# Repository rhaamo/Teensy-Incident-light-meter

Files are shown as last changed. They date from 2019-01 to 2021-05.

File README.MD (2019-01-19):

Teensy Light Meter
--------

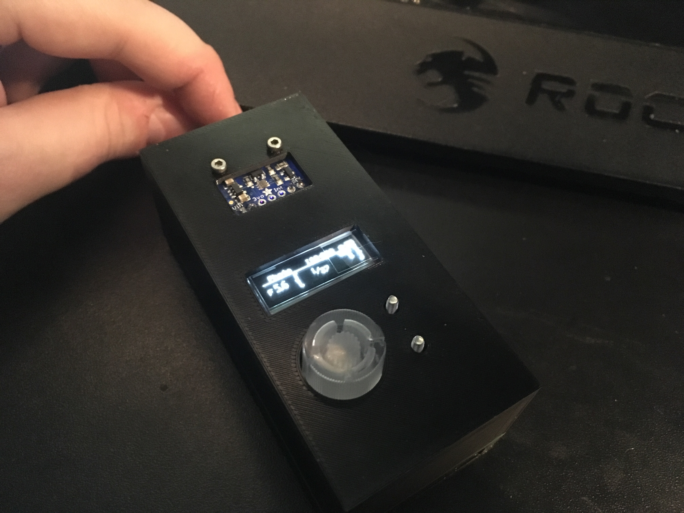
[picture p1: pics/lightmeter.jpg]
Product


### Links

 * <a href="./CALIBRATION.md">Calibration and notes</a>
 * <a href="./USAGE.md">How to use the firmware</a>
 * See the pics folder for more pictures

### Software

    $ git clone
    $ cd project/LightMeterV2
    $ pio lib install
    $ pio run
    $ pio run --target upload

Notes:
  The TSL25x1 lib I use is either custom, or hacked from anoter one. We setup the sensor and powerup on setup(), then let it run freely.

  The sensor do it's integration time by itself, we NEVER poweroff the sensor, then we read the value as the loop loops.

  This is done to avoid the 120ms*integrationTime etc. delay, the loop is ultra fast, then buttons are reactive.

  And we can then set the sensor to a high integration value without having 500ms delay introduced in the loop.

### Notes

The Light Meter isn't super slim, but not too big, it could get 5mm less easily if the pins connecting the teensyview were trimmed.

Without trimming everything used is stock without modifications. Also the OLED display PCB is way bigger than the LCD itself, and that forbig to reduce by ~3mm without having an ugly PCB popping out. Trimming the pins will be envisaged in the future.

The choosen battery was a BL-5C because I have one spare, but any with a JST connector would do the job, only the middle part and bottom of the enclosure would need redesign. The battery connector is some sort of wire bended, passed through a hole and glued after soldering. Not the best but I didn't wanted to wait a month to get a small 3-pins 3mm pitch battery connector to design the enclosure.

The stock BL-5C, genuine, is a 1000mAh battery, the Light Meter, with sensor free-running is consuming about 40mA according to the battery charger, which allows between 17 and 25 hours of continus running, in theory. You can still easily swap battery anyway, just bring the right screwdriver, and spare charged batteries with you.

The USB data is hard wired between the D+/D- pads of the teensy to the battery babysitter, allowing to program the teensy from the battery charger directly without doing anything, reset button is useless as we are using the stock teensy bootloader, permitting remote flash and reboot.

The TSL2591 doesn't permit changing I2C address, you can only have one.

### Todo

 - Design some sort of sliding window to protect the sensor
 - Games, because why not ?

### Hardware

Uses the following:

* [Teensy 3.2](https://www.sparkfun.com/products/13736)
* [TeensyView](https://www.sparkfun.com/products/14048) (ALTERNATE mode)
* [TSL2591 HDR Light Sensor](https://www.adafruit.com/product/1980)
* [Battery Babysitter](https://www.sparkfun.com/products/13777)
* [Rotary Encoder with Red/Green led](https://www.digikey.fr/product-detail/fr/bourns-inc/PEL12D-4225S-S2024/PEL12D-4225S-S2024-ND/2498880)
* [Knob, transparent](https://www.digikey.fr/product-detail/fr/sparkfun-electronics/COM-10597/1568-1838-ND/7229845)
* Battery: BL-5C (1000mAh nokia battery)
* Mini switch: 6mm push button
* Diode: 1N4148
* Transistor: 2N3940, TO-92
* Resistor: 4.7k
* Capacitor: 10uF, radial, polarised
* A PCB from the PCB folder

Some build notes :
 - The battery can be either connected from the JST connector (DIY enclosure) or from the pads right next to it (provided enclosure)
 - The D+ and D- from USB should be soldered on the teensy first before soldering it to the PCB, make sure to mark with a marker the D- wire. Then after soldering the teensy and the babysitter, twist the two DATA wires and solder them accordingly to the babysitter very small pads.
 - The TSL2591 use four wire (Vcc, GND, SDA, SCL) and ideally use two small connectors, allowing for quick disconnect, for either hacking or easy replacement.
 - The TeensyView needs to be in ALTERNATE mode, cut some jumper pads and solder the others before sticking the OLED glass. Look at Sparkfun docs for that part.
 - The Alternate mode is unfortunately needed because of the pins 10 & 11 which are already used for the RED and Green LEDs. A next revision can change that.
 - The TeensyView pins are connected by using standard "long" headers, see ```pics/main_pcb_battery_babysitter.jpg``` for soldering. Also you will have to trim the headers by 5mm on top, to make the display closed to the teensy.
 - You have to put the battery babysitter switch to the OFF position, or it will override the power-on/off feature.

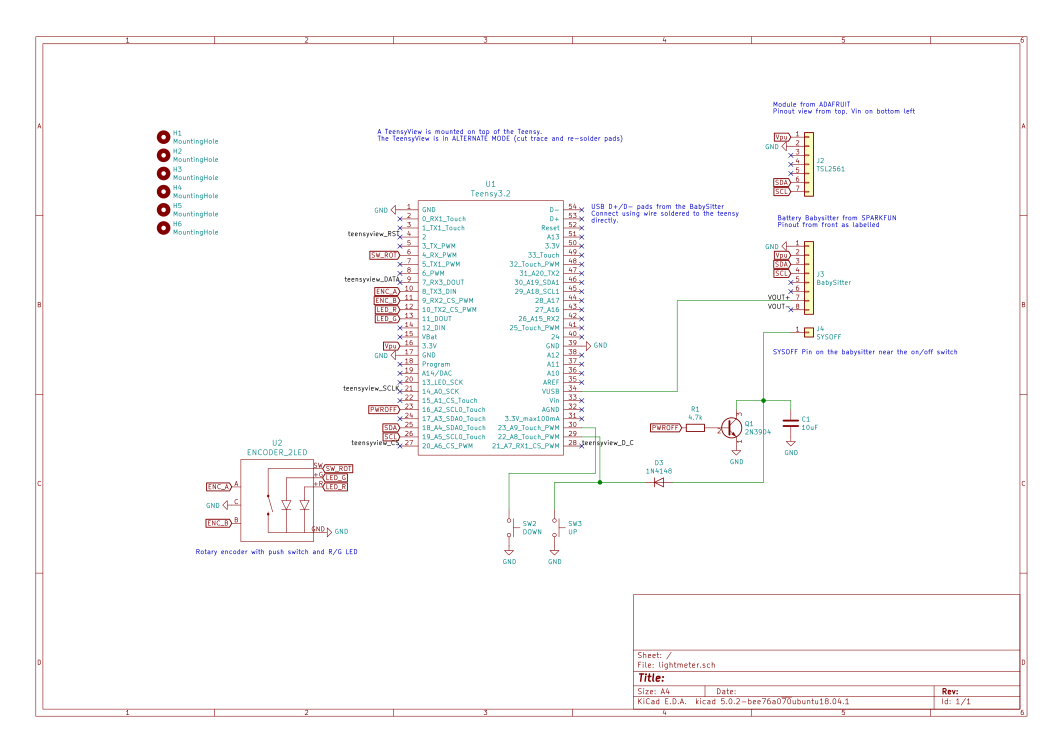
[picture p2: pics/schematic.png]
Schematic


*Schematic diagram.  Click to enlarge.*

### Enclosure

3D designed, printed, works great, to be published.

### PCB

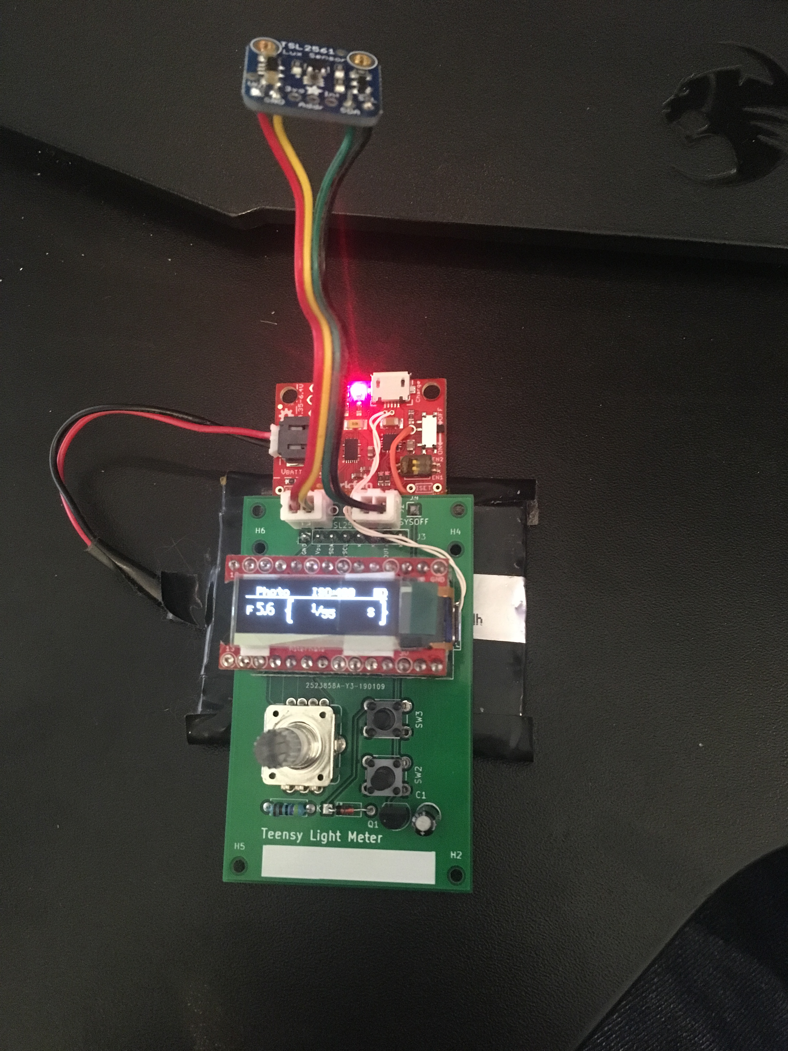
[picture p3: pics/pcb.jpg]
Innards


*An assembly*

 * Use libraries:
  * https://github.com/XenGi/teensy.pretty
  * https://github.com/XenGi/teensy_library
  * RGB Encoder Footprint and Library from https://github.com/sparkfun/Rotary_Encoder_Breakout-Illuminated

### License

Uses code from:
  * https://github.com/marshalltaylorSFE/Teensy-Incident-light-meter
  * https://github.com/kevinagnes/diycolorlightmeter/

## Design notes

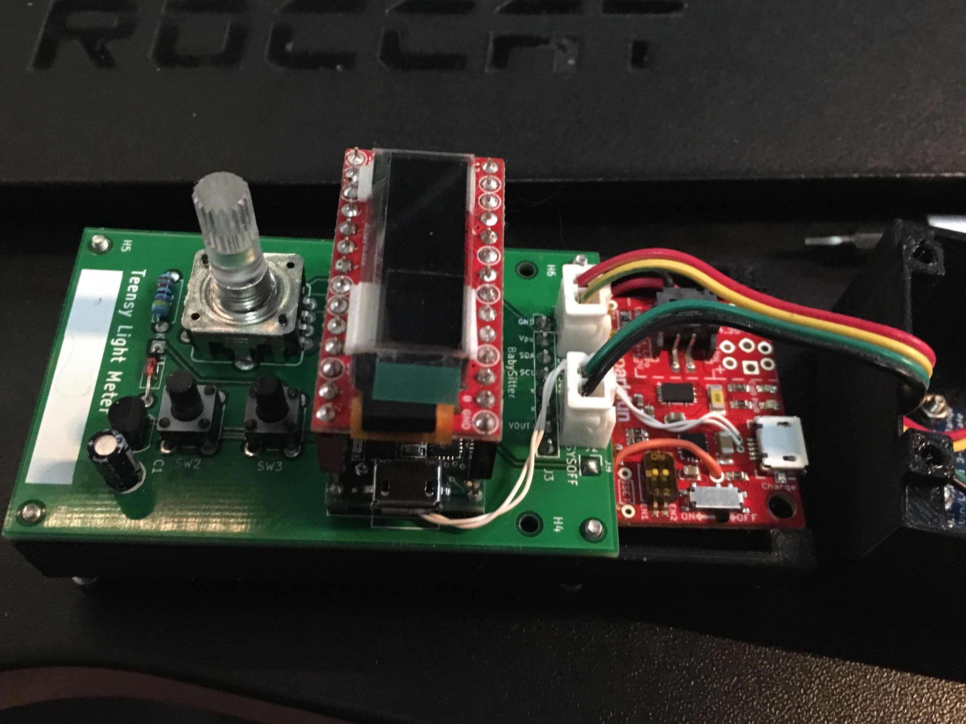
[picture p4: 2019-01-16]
pics/pcb_built_closeup.jpg

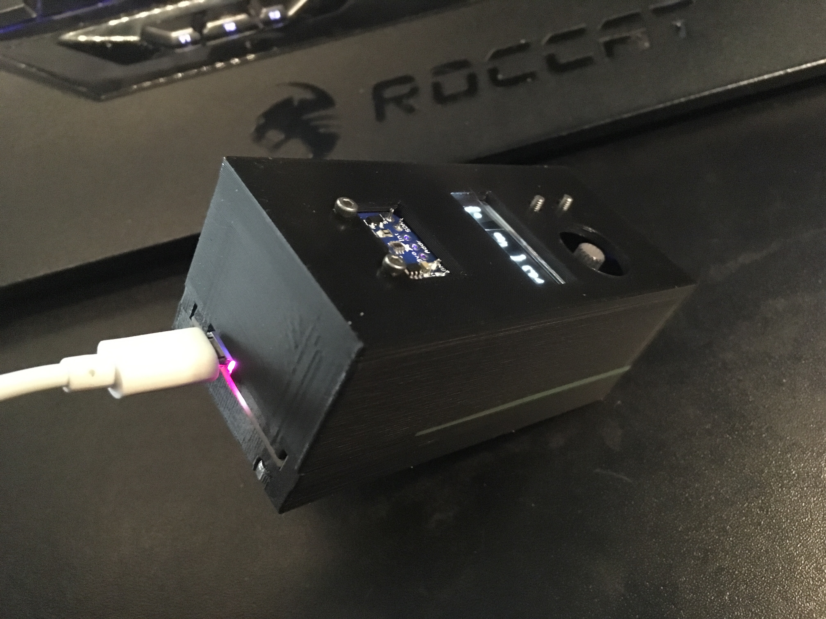
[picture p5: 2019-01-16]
pics/usb_charge.jpg

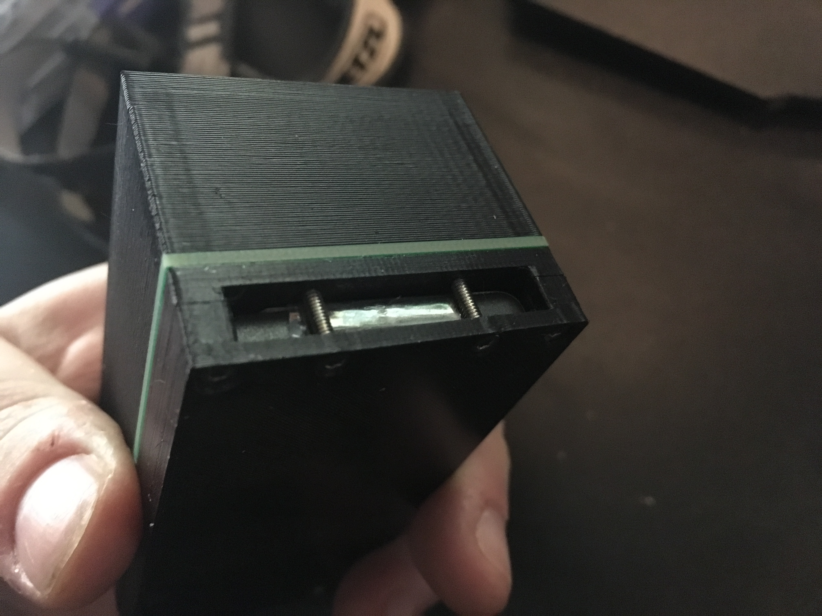
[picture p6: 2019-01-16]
pics/battery_retainer.jpg

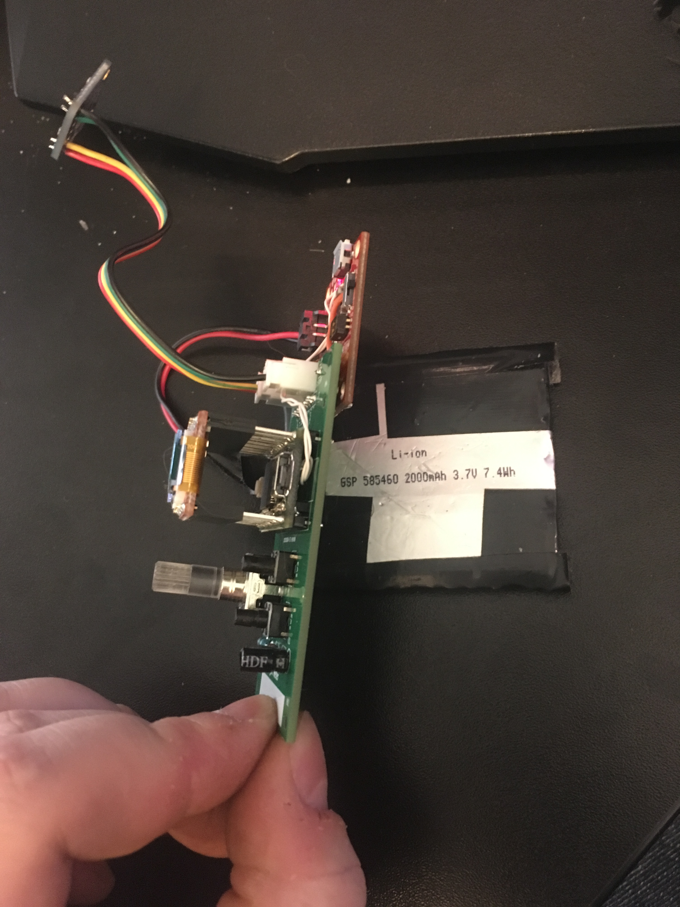
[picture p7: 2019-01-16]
pics/main_pcb_battery_babysitter.jpg

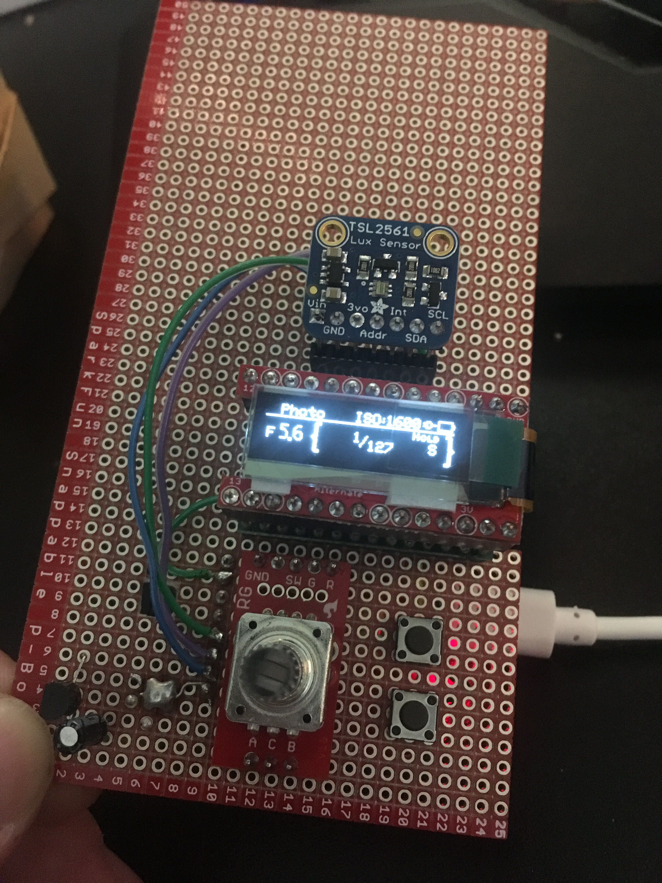
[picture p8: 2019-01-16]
pics/prototype.jpg

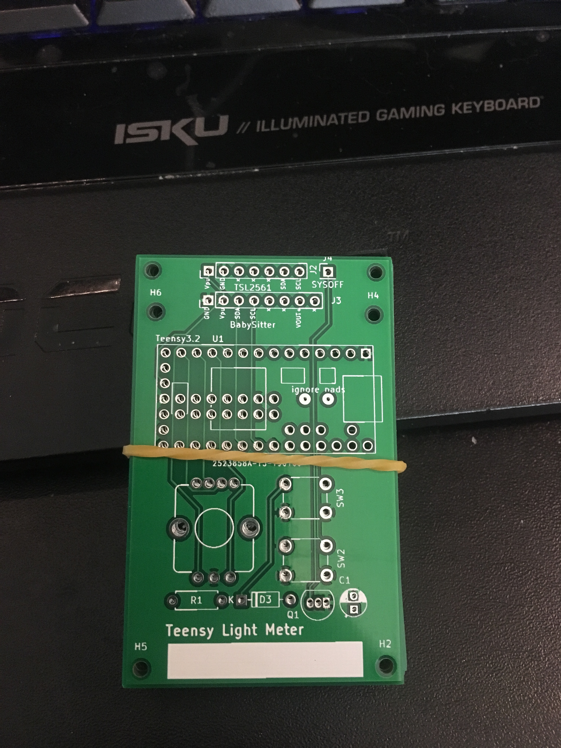
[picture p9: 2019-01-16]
pics/main_pcb.jpg

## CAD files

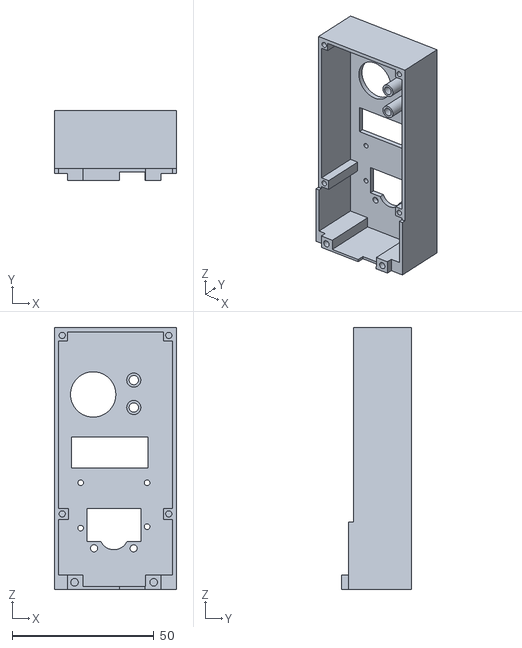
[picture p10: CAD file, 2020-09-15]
enclosure_v1/top.stl
43.2 x 24.6 x 92.5

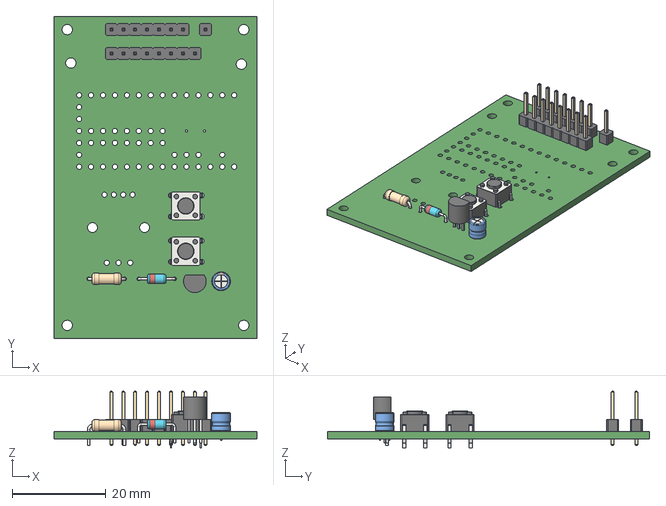
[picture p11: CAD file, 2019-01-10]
PCB/lightmeter.step
43.2 x 68.6 x 12.0 mm

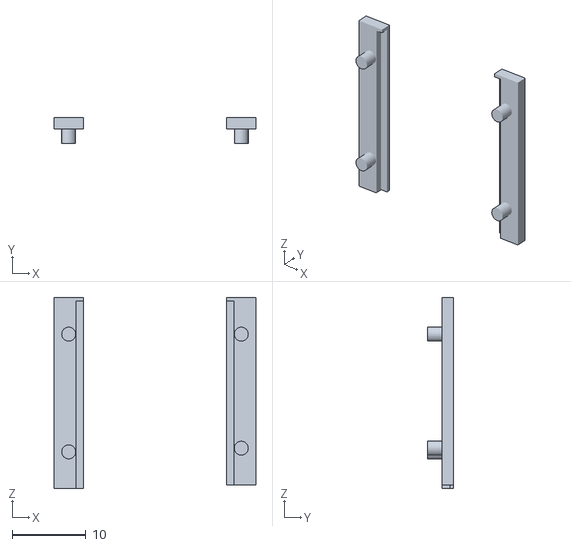
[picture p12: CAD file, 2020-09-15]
enclosure_v1/cover slides.stl
27.4 x 3.60 x 26.0

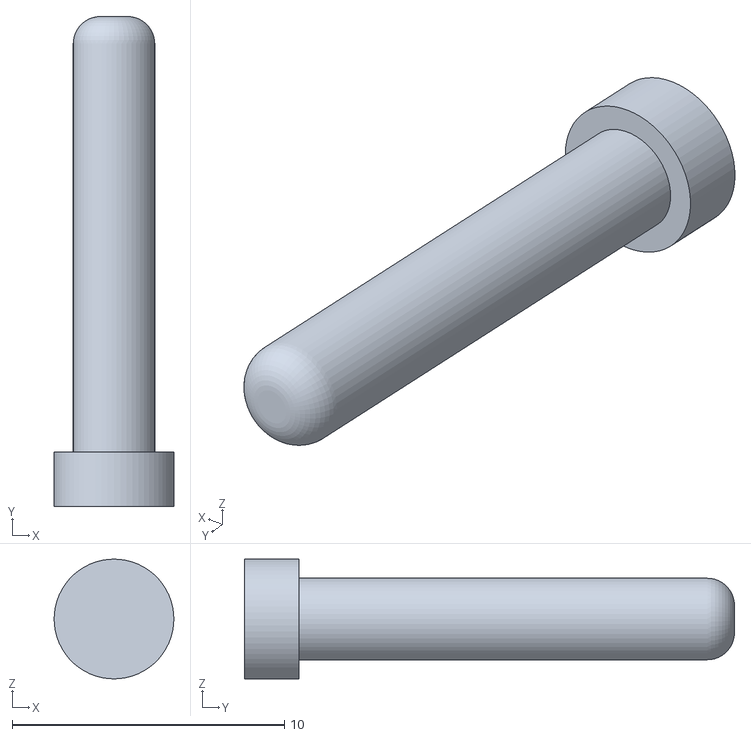
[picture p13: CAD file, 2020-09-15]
enclosure_v1/pb_extender_x2.stl
4.40 x 18.0 x 4.40

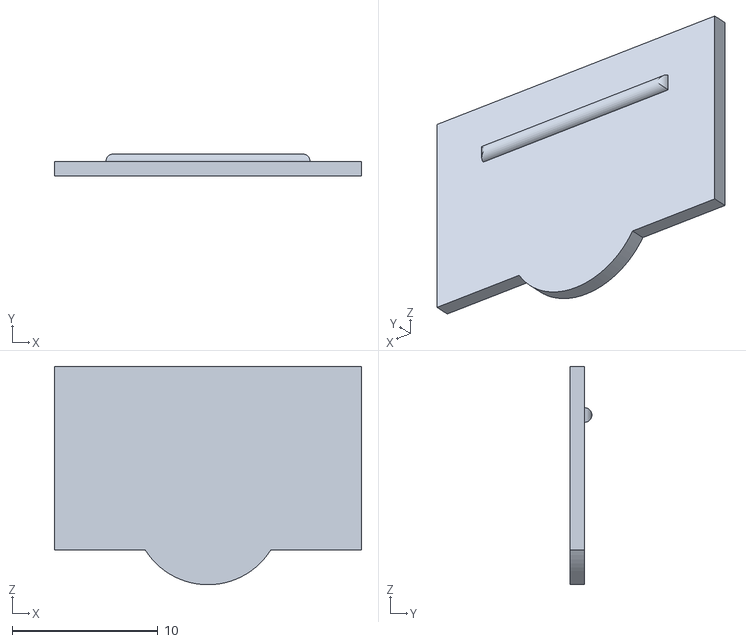
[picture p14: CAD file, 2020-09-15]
enclosure_v1/cover.stl
21.1 x 1.50 x 15.0

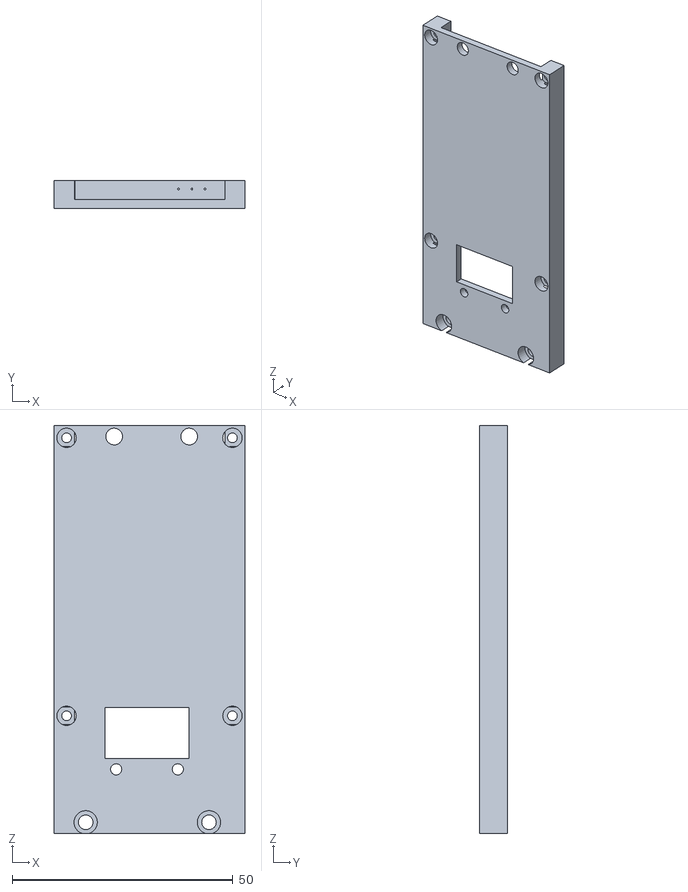
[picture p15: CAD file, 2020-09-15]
enclosure_v1/bottom.stl
43.2 x 6.30 x 92.5

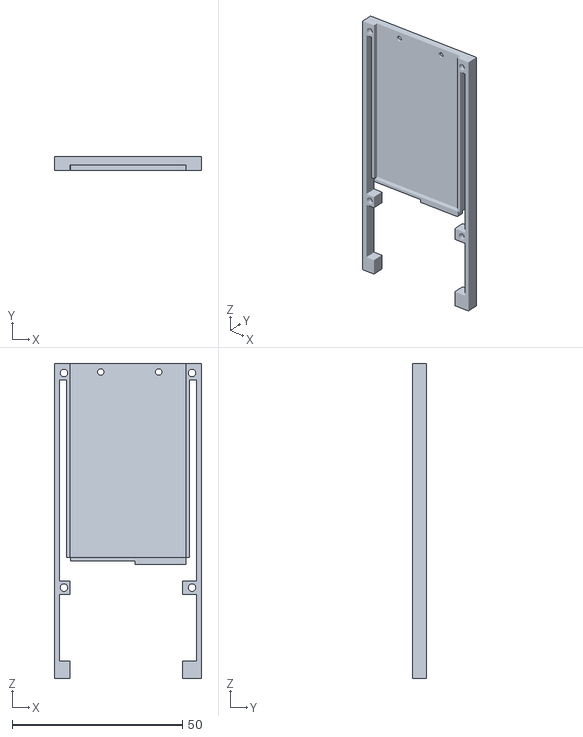
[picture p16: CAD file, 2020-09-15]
enclosure_v1/middle.stl
43.2 x 4.10 x 92.5

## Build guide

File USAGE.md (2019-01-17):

# Usage of the Light Meter firmware

## Physical

The encoder is also a push-button, and made to be translucent as the cap, and lighted with a RED and GREEN leds.

The top button is the power-on, and previous-menu, the bottom one is next-menu.

To power-on the light meter, press the top button for a few seconds.

To power-down the light meter, go to the system menu and press the encoder. An auto-power down is also implemented, if there is no knob or button handling in one hour, it will auto power-off to save battery life.

If charging, a small "plug" icon will appears on left of the battery indicator on top-right.

## Menus, in order

### Photo mode

Rotate the encoder to change aperture, the exposure meter is free-running, in order to take a still measure, point the device at your subject, then blindly press the encoder pushbutton, then look back at the screen. The light meter is now on hold, notified by a small "Hold" displayed on top right.

Press again the encoder to get back to free-running mode.

While on Hold you can rotate the encoder and get speed for different aperture !

### Cine/Video mode

Same as Photo mode, rotating the encoder change the film speed, the encoder press will switch to Hold.

### ISO selection

Rotate the encoder to choose your current ISO speed. Upon changing menu, the selected ISO will be saved in EEPROM and read back on power-on.

### System

This menu displays the following:

 - top-left: OK ! or NOBATT ! if battery present or not
 - top-right: battery voltage
 - bottom-left: battery percentage
 - bottom-right: charge or discharge rate, -40mA means the light meter consumes 40mA to run, a positive number means it is recharging.

 Press the encoder to shutdown the light meter.

 ### Lux

 This menu displays raw values from the sensor:

  - top-left: RAW infrared value
  - top-right: RAW visible value
  - bottom: calculated LUX value

  You can also press the encoder button to Hold the LUX value, hold will be indicated on bottom right.

### Mary

Kept from the first firmware this Light Meter is based on, press the encoder, it will displays a few hearts.

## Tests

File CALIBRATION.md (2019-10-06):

# Latests informations not yet committed

The standard for calibration is ISO 2728-1974, available by finding "indian standard 10917-1984" which is the absolute same.

Key points:
- Lux to Candela formula is: Iv(candela) = Ev(lux) x square(Distance in meter from the light source)
- We use the Artithmetic film speed (ISO/ASA)

Calibration formula is:
- K = (L\*t\*S)/square of A; Where L: luminance in candala per m2 (see previous formula for lux to cd/m2); t: shutter speed in seconds; S: arithmetic film speed; A: f-number

This is the part 6 of page 7 of the IS, Table 2 on next page present the values of shutter speed, f-number and ISO (S) for each calibration step.

From the standard the light is a 4700K tungsten with a 2855,6K light filter.

For practical reasons I will uses a 2850K light bulb and a diffuser, which is nearly enough for this, without costing an arm to get (filter and light bulb).

A calibration from theses informations have not yet been done, this file will be updated when done, and the right K value determinated.

# Notes

Incident light metering is done on the subject, sensor is covered with a translucent plastic dome, pointing at the light source.

Reflected light metering is done facing the subject, or more precisely, the same spot as your camera, without anything covering the sensor.

My calibration is only valid for reflected metering.

I don't really know how it would be done for incident, perhaps doing a reflected calibration, then add the dome and do some magic to get the right "Dome Multiplier" value ?

# My calibration

I've done some "calibration" indoor, a 18% grey card (~A4 size) with ~5m away a studio lamp pointing at it, all day, providing a constant light source.

I've used a DSLR, Canon 550D and fixed 50mm lens. In manual mode, ISO to 800, I've set my aperture to each available f stop between 1.8 and 22, with every shot trying to get the R, G and B histogram on the right middle as possible.

Then everything was put into a LibreOffice Calc sheet, and used a formula, basically ```(POWER(fStop, 2)*Kvalue)/(currentLux*ISO)``` to get all corresponding from the lux meter. I had then, on each line : fStop, DSLR speed ```=1/x```, formula speed (previous formula).

The currentLux was got from the DIY lux meter, pointing the grey card, more or less same spot as the DSLR, and triggered the hold function, then from the serial I reported the lux in the sheet, since it doesn't change and is consistant, it's a static value.

Then I tweaked the Kvalue, to get a curve as much matching the one as the DSLR, see screenshot right after.

The LibreOffice sheet is available as a reference in ```LightMeterV2/fstop lux calc.ods```.

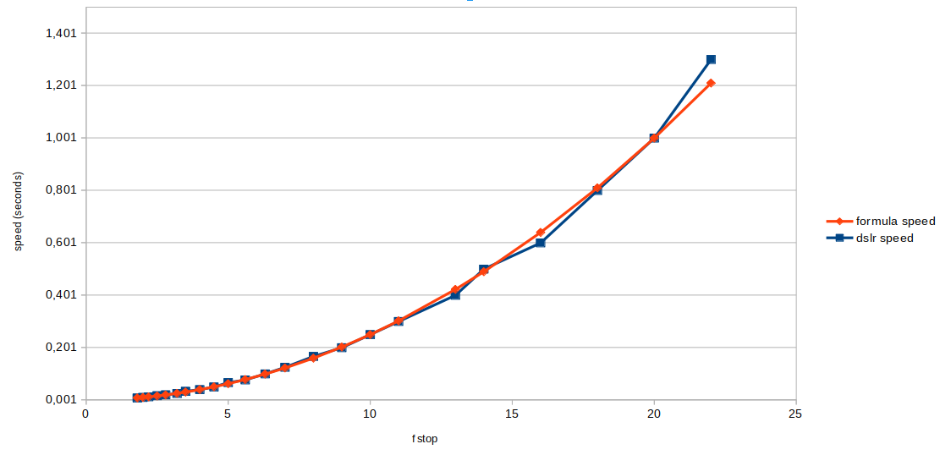
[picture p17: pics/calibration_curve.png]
calibration curve


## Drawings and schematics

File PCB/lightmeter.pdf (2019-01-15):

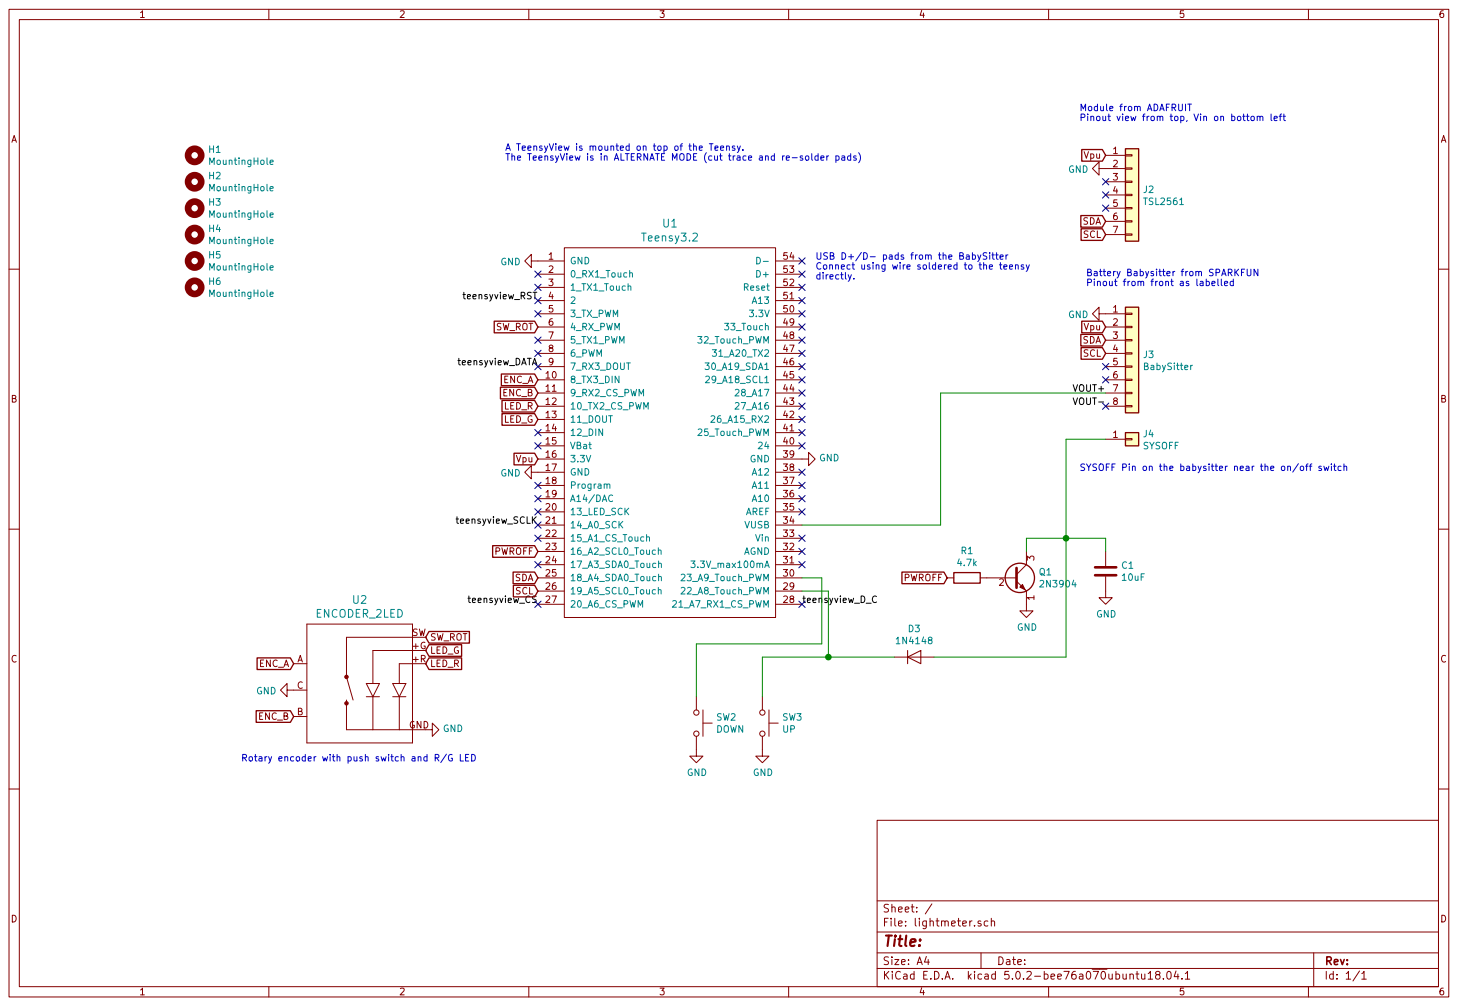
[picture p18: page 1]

J2TSL2561 Module from ADAFRUIT Pinout view from top, Vin on bottom left

A TeensyView is mounted on top of the Teensy.
The TeensyView is in ALTERNATE MODE (cut trace and re-solder pads)

Pinout from front as labelled GND

USB D+/D- pads from the BabySitter
Connect using wire soldered to the teensy

Battery Babysitter from SPARKFUN

File: lightmeter.sch Sheet: /
Id: 1/1 Title:

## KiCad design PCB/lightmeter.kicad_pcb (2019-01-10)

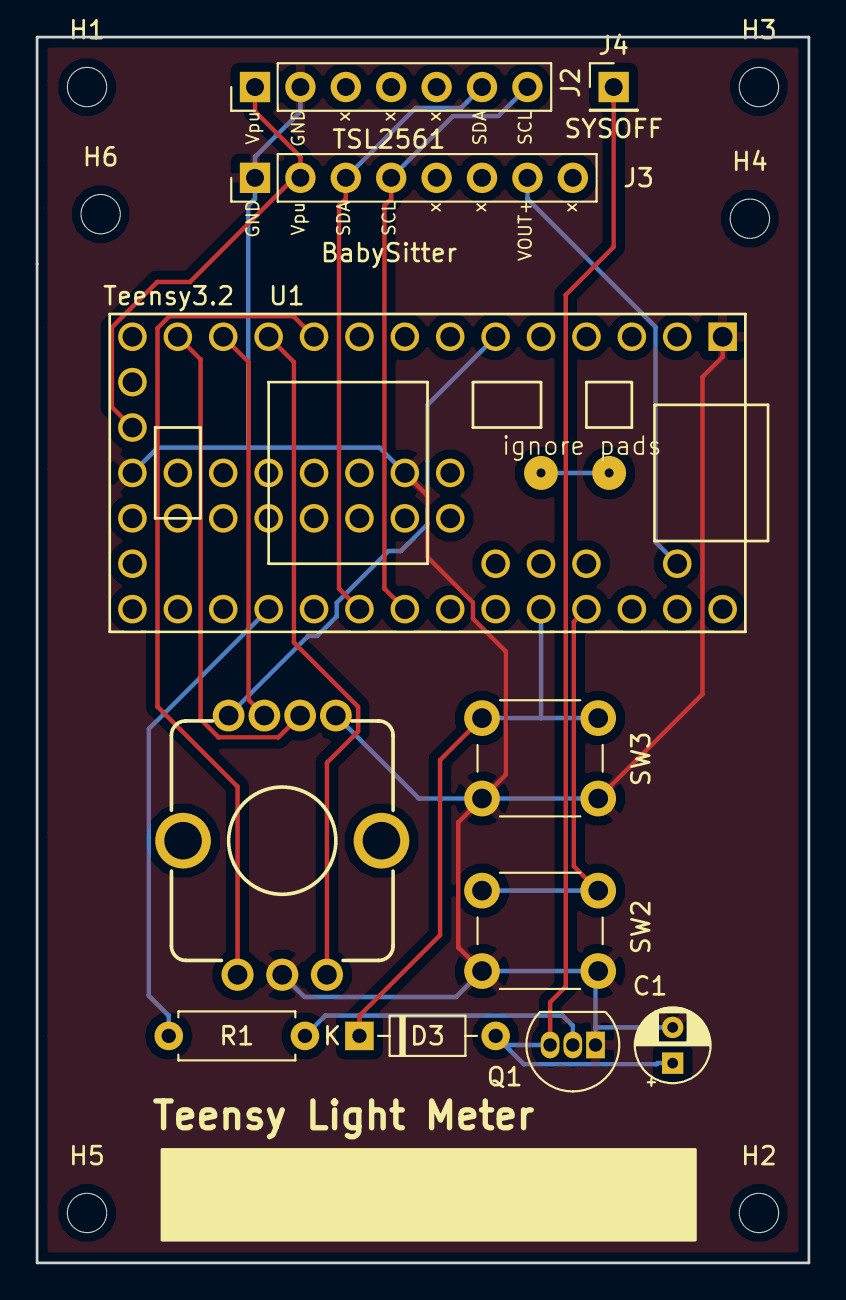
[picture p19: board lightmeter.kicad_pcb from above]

Board: 2 copper layers, 43.2 x 68.6 mm, 17 parts (0 on the bottom side), 15 nets.

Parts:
C1: 10uF; CP_Radial_D4.0mm_P2.00mm
D3: 1N4148; D_DO-35_SOD27_P7.62mm_Horizontal
H1, H2, H3, H4, H5, H6: MountingHole; MountingHole_2.2mm_M2
J2: TSL2561; PinHeader_1x07_P2.54mm_Vertical
J3: BabySitter; PinHeader_1x08_P2.54mm_Vertical
J4: SYSOFF; PinHeader_1x01_P2.54mm_Vertical
Q1: 2N3904; TO-92_Inline
R1: 4.7k; R_Axial_DIN0207_L6.3mm_D2.5mm_P7.62mm_Horizontal
SW2: DOWN; SW_PUSH_6mm
SW3: UP; SW_PUSH_6mm
U1: Teensy3.2; Teensy30_31_32_LC
U2: ENCODER_2LED; ENCODER_LED_2_KIT

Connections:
/VOUT+: J3.7, U1.34
ENC_A: U1.10, U2.A
ENC_B: U1.11, U2.B
GND: C1.2, J2.2, J3.1, Q1.1, SW2.2, SW3.2, U1.1, U1.17, U1.39, U2.C, U2.GND
LED_G: U1.13, U2.+G
LED_R: U1.12, U2.+R
unnamed: C1.1, D3.2, J4.1, Q1.3
unnamed: D3.1, SW3.1, U1.29
unnamed: Q1.2, R1.1
unnamed: SW2.1, U1.30
PWROFF: R1.2, U1.23
SCL: J2.7, J3.4, U1.26
SDA: J2.6, J3.3, U1.25
SW_ROT: U1.6, U2.SW
Vpu: J2.1, J3.2, U1.16

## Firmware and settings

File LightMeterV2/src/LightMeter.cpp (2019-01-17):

//
// Copyright 2018 marshalltaylorSFE & Dashie <dashie@sigpipe.me>
//
#include "LightMeter.h"  // NOLINT

Adafruit_TSL2591 luxMeter = Adafruit_TSL2591(2591);

OLEDFunctions oled(PIN_RESET, PIN_DC, PIN_CS, PIN_SCK, PIN_MOSI);

LightMeter myLightMeter;

// User Inputs
Encoder uiEncoder(9, 8);
PushButton uiPbEnter = PushButton(4);
PushButton uiPbUp = PushButton(22);
PushButton uiPbDown = PushButton(23);

JLed ledGreen = JLed(PIN_LED_OK);
JLed ledRed = JLed(PIN_LED_KO);

// Boing boing
void cfgPushButton(Bounce &bB) {  // NOLINT
    bB.interval(20);              // set to 15ms, default 10ms
}

/*
 * Menu order:
 * Photo -> Video -> SetISO -> System -> DisplayLux ->
 *  Mary -> StopRange -> Calibration -> IntegrationTime
 *
 * Button down = next menu, up = previous menu
 */
void onButtonReleased(Button &btn, uint16_t duration) {  // NOLINT
    myLightMeter.lastActivity = millis();                // reset counter

    Serial.println("button pressed");
    // UP button
    if (btn.is(uiPbUp)) {
        if (myLightMeter.state == MDisplayPhotoValue) {
            // top of menu
        } else if (myLightMeter.state == MDisplayVideoValue) {
            myLightMeter.state = MDisplayPhotoValueInit;
        } else if (myLightMeter.state == MSetISO) {
            myLightMeter.saveConfigUser();
            myLightMeter.state = MDisplayVideoValueInit;
        } else if (myLightMeter.state == MSystem) {
            myLightMeter.state = MSetISOInit;
        } else if (myLightMeter.state == MDisplayLuxValue) {
            myLightMeter.state = MSystemInit;
        } else if (myLightMeter.state == MMary) {
            myLightMeter.state = MDisplayLuxValueInit;
        }

        // DOWN button
    } else if (btn.is(uiPbDown)) {
        if (myLightMeter.state == MDisplayPhotoValue) {
            myLightMeter.state = MDisplayVideoValueInit;
        } else if (myLightMeter.state == MDisplayVideoValue) {
            myLightMeter.state = MSetISOInit;
        } else if (myLightMeter.state == MSetISO) {
            myLightMeter.saveConfigUser();
            myLightMeter.state = MSystemInit;
        } else if (myLightMeter.state == MSystem) {
            myLightMeter.state = MDisplayLuxValueInit;
        } else if (myLightMeter.state == MDisplayLuxValue) {
            myLightMeter.state = MMaryInit;
        } else if (myLightMeter.state == MMary) {
            // bottom of menu
        }

        // ENTER button
    } else if (btn.is(uiPbEnter)) {
        Serial.println("ENTER button pressed");
        if (myLightMeter.state == MSystem) {
            myLightMeter.powerDown(false);

            myLightMeter.state = MSystemInit;
        } else if (myLightMeter.state == MMary) {
            if (myLightMeter.heartCount < 7) {
                oled.drawHeart(myLightMeter.heartCount * 18, 12);
                ledRed.Off();
                ledGreen.Blink(100, 100).Repeat(2);
                myLightMeter.heartCount++;
            }

            // End of menu
            // Trigger stats
        } else if (myLightMeter.triggerState == hSRun) {
            myLightMeter.triggerState = hSHeld;
        } else if (myLightMeter.triggerState == hSHeld) {
            myLightMeter.triggerState = hSRun;
        }
    }
}

void setup() {
    // Assert power on pin
    pinMode(PIN_POWER_ON, OUTPUT);
    digitalWrite(PIN_POWER_ON, HIGH);
    Serial.begin(115200);
    // while(!Serial);

    // Leds output, off by default
    pinMode(PIN_LED_OK, OUTPUT);
    digitalWrite(PIN_LED_OK, LOW);
    pinMode(PIN_LED_KO, OUTPUT);
    digitalWrite(PIN_LED_KO, LOW);

    // begin() will return true if communication is successful
    if (!lipo.begin()) {
        // bad state happenings
        myLightMeter.lipoGood = false;
        Serial.println("No battery or battery issue.");
    } else {
        myLightMeter.lipoGood = true;
        lipo.setCapacity(LIPO_CAPACITY);
        Serial.println("Battery should be good.");
    }

    oled.begin();      // Initialize the OLED
    oled.clear(ALL);   // Clear the display's internal memory
    oled.drawLogo();   // Display custom logo
    delay(2000);       // Delay 1200 ms
    oled.clear(PAGE);  // Clear the buffer.

    // Setup Pushbuttons and encoder
    uiPbEnter.configureButton(cfgPushButton);
    uiPbUp.configureButton(cfgPushButton);
    uiPbDown.configureButton(cfgPushButton);

    uiPbEnter.onRelease(onButtonReleased);
    uiPbUp.onRelease(onButtonReleased);
    uiPbDown.onRelease(onButtonReleased);

    luxMeter.begin();
    luxMeter.setTiming(SENSOR_INTTIME_DEFAULT);
    luxMeter.enable();
}

void loop() {
    delay(10);  // wait 10ms

    if (millis() - myLightMeter.lastActivity > SLEEP_AFTER) {
        myLightMeter.powerDown(true);
    }

    myLightMeter.process();
    // Serial.println("loop");
}

// Constructor, do basic init here
LightMeter::LightMeter(void) {
    // Defaults
    lux = 0;
    lipoGood = false;
    triggerState = hSRun;

    // Load user configuration from EEPROM
    loadConfigUser();
}

// Load user config, but first check if datas might be valid
void LightMeter::loadConfigUser() {
    // Get marker stored in EEPROM
    String marker;
    EEPROM.get(addrMarker, marker);

    if (marker == progName) {
        // Marker match, get user config
        EEPROM.get(addrConfigUser, ConfigUser);
    } else {
        // EEPROM is empty, generate the default content
        saveConfigUser();
    }
}

void LightMeter::saveConfigUser() {
    // Our config struct can't be bigger than the position of the MARKER in the
    // EEPROM 2000 for a teensy 3.2, 1000 for a 2.0, 4000 for a >= 3.5
    if (sizeof(ConfigUser) >= addrMarker) {
        Serial.println("sizeof(ConfigUser) >= 2000 !!!");
        ledStatus(LED_KO, 500, 3);
        return;
    }
    EEPROM.put(addrConfigUser, ConfigUser);
    EEPROM.put(addrMarker, progName);
    ledStatus(LED_OK, 300, 1);
}

// Sleep time
void LightMeter::powerDown(bool autosleep) {
    oled.clear(PAGE);
    oled.setFontType(1);
    oled.setCursor(6, 6);
    if (autosleep) {
        oled.print("Auto sleep zZz");
    } else {
        oled.print("Power down.");
    }
    oled.display();
    delay(1000);

    // Last minute things
    saveConfigUser();
    delay(10);

    // Try to shutdown
    digitalWrite(PIN_POWER_ON, LOW);

    myLightMeter.ledStatus(LED_KO, 1000, 3);

    // Oops failed
    lastActivity = millis();  // reset counter
    delay(4000);

    oled.clear(PAGE);
    oled.setCursor(6, 6);
    oled.print("Failed !");
    oled.display();
    delay(1000);

    oled.setFontType(0);
    oled.clear(PAGE);
    oled.display();

    myLightMeter.state = MSystemInit;
}

// state 0 OK, state 1 KO
void LightMeter::ledStatus(int state, int delay, int repeat) {
    if (state == 0) {
        ledGreen.Blink(delay, delay).Repeat(repeat);
        ledRed.Off();
    } else {
        ledRed.Blink(delay, delay).Repeat(repeat);
        ledGreen.Off();
    }
}

void LightMeter::getRawLux() {
    if (needHigh) {
        luxMeter.setGain(TSL2591_GAIN_HIGH);
        luxMeter.setTiming(SENSOR_INTTIME_HIGH);  // 200ms
    } else {
        luxMeter.setGain(TSL2591_GAIN_LOW);
        luxMeter.setTiming(SENSOR_INTTIME_DEFAULT);  // 400ms
    }

    sensors_event_t event;
    luxMeter.getEvent(&event);
    float tempLux = event.light;
    // When sensor get saturated (normally in transition between gain)
    // Lux value is restored to 201 for an effective change in Gain
    // (from 428x to 1x)
    // Overflow is displayed indicating that this value is not correct
    if ((event.light == 0) | (event.light > 4294966000.0) |
        (event.light < -4294966000.0)) {
        tempLux = 201;
        overflow = 1;
    } else {
        overflow = 0;
    }

    tempLux =
        tempLux *
        DomeMultiplier;  // DomeMultiplier = 2.3 (calibration) INCIDENT only
    if (tempLux < 40) {
        needHigh = 1;
    }  // ~ 1 +1/3 OFFSET (*0.26 in lux calibration)
    if (tempLux > 200) {
        needHigh = 0;
    }  // Turns off High hain
    // if (needHigh) {tempLux = tempLux*.26;}   // OFFSET corrected

    if (triggerState == hSRun) {
        lux = tempLux;
    }
}

// Get and display calculated fStop or speed
void LightMeter::getLuxAndCompute(bool fstop) {
    getRawLux();
    float value;

    /*
     * exposure time = stop squared * K / ( ISO * Lux )
     * f x f    Lux x ISO
     * -----  = ---------
     * shut       K cal
     */

    if (fstop) {
        // T value; Shutter time, in seconds
        value = pow(fStopTable[ConfigUser.fStopSetting], 2) * KValue /
                (lux * (isoTable[ConfigUser.isoSetting]));
    } else {
        // N value; Aperture
        value = sqrt((exposureTable[ConfigUser.exposureSetting] * lux *
                      isoTable[ConfigUser.isoSetting]) /
                     CValue);
    }
    Serial.print("lux: ");
    Serial.print(lux);
    Serial.print(" ;stop: ");
    Serial.print(fStopTable[ConfigUser.fStopSetting]);
    Serial.print(" ;speed: ");
    if (value < 1) {
        Serial.print("1/");
    }
    Serial.print(value);
    Serial.print(" ;gain: ");
    tsl2591Gain_t gain = luxMeter.getGain();
    switch (gain) {
        case TSL2591_GAIN_LOW:
            Serial.print(F("1x (Low)"));
            break;
        case TSL2591_GAIN_MED:
            Serial.print(F("25x (Medium)"));
            break;
        case TSL2591_GAIN_HIGH:
            Serial.print(F("428x (High)"));
            break;
        case TSL2591_GAIN_MAX:
            Serial.print(F("9876x (Max)"));
            break;
    }
    Serial.print(" ;timing: ");
    Serial.print((luxMeter.getTiming() + 1) * 100, DEC);
    Serial.println(F(" ms"));

    oled.eraseLowerArea();
    oled.drawLeftBracket(37, 10);
    oled.drawRightBracket(122, 10);
    if (fstop) {
        oled.drawFNumStyle1(fStopTable[ConfigUser.fStopSetting], 2, 13);
        oled.drawExposureStyle1(value, 60, 14);
    } else {
        oled.drawExposureStyle2(exposureTable[ConfigUser.exposureSetting], 2,
                                13);
        oled.drawFNumStyle2(value, 60, 14);
    }
    if (overflow) {
        oled.drawNo(33, 12);
        ledStatus(LED_KO, 500, 3);
    }
    if (triggerState == hSHeld) {
        oled.holdStyle1(100, 10);
    }
    if (fstop) {
        oled.setCursor(111, 17);
        oled.print("S");
    }
}

// Get and display bare LUX value
void LightMeter::getLux() {
    (void)getRawLux();

    // From getRawLux()
    sensor_t sensor;
    luxMeter.getSensor(&sensor);

    if (needHigh) {
        luxMeter.setGain(TSL2591_GAIN_HIGH);
    } else {
        luxMeter.setGain(TSL2591_GAIN_LOW);
    }
    // END

    // From Adafruit
    uint16_t ir, full;
    uint32_t lum = luxMeter.getFullLuminosity();
    lum = luxMeter.getFullLuminosity();
    ir = lum >> 16;
    full = lum & 0xFFFF;
    // END

    oled.setCursor(0, 11);
    oled.print("ir: ");
    oled.print(ir);
    oled.print("   ");

    oled.setCursor(64, 11);
    oled.print("vis: ");
    oled.print(full - ir);
    oled.print("   ");

    // Print out the result
    oled.setCursor(0, 20);
    oled.print("lux:");
    oled.print(lux);
    oled.print("   ");

    oled.setCursor(116, 20);
    if (!overflow) {
        oled.print("  ");
    } else {
        oled.drawNo(120, 20);
        ledStatus(LED_KO, 1000, 3);
    }
    if (triggerState == hSHeld) {
        oled.holdStyle1(100, 22);
    } else {
        // Clear hold
        oled.setCursor(100, 22);
        oled.print("    ");
    }
}

void LightMeter::process(void) {
    // Update buttons states
    uiPbEnter.update();
    uiPbUp.update();
    uiPbDown.update();
    uint32_t curEncoderPos = uiEncoder.read();

    ledGreen.Update();
    ledRed.Update();

    // Do not update display for now
    bool drawDisplay = false;

    drawDisplay = oled.drawBatteryWidget();

    // Handle current set state
    switch (state) {
        case Minit:
            // Initial state
            oled.clear(PAGE);
            drawDisplay = true;
            state = MDisplayPhotoValueInit;
            break;

        case MDisplayPhotoValueInit:
            // Init photo light metering
            drawDisplay = true;
            oled.clear(PAGE);
            oled.drawMenu("Photo", isoTable[ConfigUser.isoSetting], false,
                          true);
            state = MDisplayPhotoValue;
            break;

        case MDisplayPhotoValue:
            // Photo light metering
            // Did the encoder move ?
            if (curEncoderPos != lastEncoderPos) {
                // yes
                if (curEncoderPos <= lastEncoderPos - ROT_ENC_DETENTS_COUNTS) {
                    // moved down
                    if (ConfigUser.fStopSetting > 0) {
                        ConfigUser.fStopSetting--;
                    }
                } else if (curEncoderPos >=
                           lastEncoderPos + ROT_ENC_DETENTS_COUNTS) {
                    // moved up
                    if (ConfigUser.fStopSetting < FSTOP_COUNT - 1) {
                        ConfigUser.fStopSetting++;
                    }
                }
            }

            // Get measurements and display it
            getLuxAndCompute(true);  // T value
            drawDisplay = true;

            break;

        case MDisplayVideoValueInit:
            drawDisplay = true;
            oled.clear(PAGE);
            oled.drawMenu("Video", isoTable[ConfigUser.isoSetting], true, true);
            state = MDisplayVideoValue;
            break;

        case MDisplayVideoValue:
            // Video light metering
            // Did the encoder move ?
            if (curEncoderPos != lastEncoderPos) {
                // yes
                if (curEncoderPos <= lastEncoderPos - ROT_ENC_DETENTS_COUNTS) {
                    // moved down
                    if (ConfigUser.exposureSetting > 0) {
                        ConfigUser.exposureSetting--;
                    }
                } else if (curEncoderPos >=
                           lastEncoderPos + ROT_ENC_DETENTS_COUNTS) {
                    // moved up
                    if (ConfigUser.exposureSetting < EXPOSURE_COUNT - 1) {
                        ConfigUser.exposureSetting++;
                    }
                }
            }

            // Get measurements and display it
            getLuxAndCompute(false);  // N value
            drawDisplay = true;

            break;

        case MSetISOInit:
            drawDisplay = true;
            oled.clear(PAGE);
            // Menu part
            oled.drawMenu("ISO", true, true);

            // Draw last value
            oled.drawISOScale(ConfigUser.isoSetting);

            state = MSetISO;
            break;

        case MSetISO:
            // ISO Selection
            // Did the encoder move ?
            if (curEncoderPos != lastEncoderPos) {
                // yes
                drawDisplay = true;
                oled.setCursor(0, 11);
                oled.print("      ");

                if (curEncoderPos <= lastEncoderPos - ROT_ENC_DETENTS_COUNTS) {
                    // moved down
                    if (ConfigUser.isoSetting > 0) {
                        Serial.println("ISO--");
                        Serial.println(ConfigUser.isoSetting);
                        Serial.println(isoTable[ConfigUser.isoSetting]);
                        ConfigUser.isoSetting--;
                    }
                } else if (curEncoderPos >=
                           lastEncoderPos + ROT_ENC_DETENTS_COUNTS) {
                    // moved up
                    if (ConfigUser.isoSetting < isoTableSize - 1) {
                        Serial.println("ISO++");
                        Serial.println(ConfigUser.isoSetting);
                        Serial.println(isoTable[ConfigUser.isoSetting]);
                        ConfigUser.isoSetting++;
                    }
                }

                // Draw new value
                oled.drawISOScale(ConfigUser.isoSetting);
            }

            break;

        case MSystemInit:
            drawDisplay = true;
            oled.clear(PAGE);

            oled.drawMenu("System", true, false);

            oled.setCursor(64, 11);
            oled.print(static_cast<float>(lipo.voltage()) / LIPO_CAPACITY, 2);
            oled.print("V");

            oled.setCursor(0, 20);
            oled.print(static_cast<float>(lipo.soc()), 0);
            oled.print("%");

            state = MSystem;
            break;

        case MSystem:
            oled.setCursor(0, 11);
            if (lipoGood) {
                oled.print("OK!");
            } else {
                oled.print("NOBATT");
            }

            oled.setCursor(64, 20);
            oled.print(lipo.current(AVG));
            oled.print("mA    ");

            oled.setCursor(0, 20);
            oled.print(static_cast<float>(lipo.soc()), 0);
            oled.print("%");

            oled.setCursor(64, 11);
            oled.print(static_cast<float>(lipo.voltage()) / LIPO_CAPACITY, 2);

            // Shutdown is handled in button callback

            drawDisplay = true;

            break;

        case MDisplayLuxValueInit:
            drawDisplay = true;
            oled.clear(PAGE);

            oled.drawMenu("Lux", false, false);
            state = MDisplayLuxValue;
            break;

        case MDisplayLuxValue:
            getLux();
            drawDisplay = true;
            break;

        case MMaryInit:
            drawDisplay = true;
            oled.clear(PAGE);

            oled.drawMenu("Mary", true, false);
            heartCount = 0;
            state = MMary;
            break;

        case MMary:
            drawDisplay =
                true;  // might need special handling since it was handled
            // by if(enter pressed) if (hC < 7)
            break;

        case MFStopRangeInit:
        case MFStopRange:

        default:
            state = Minit;
            break;
    }

    // Do we need to draw the display ?
    if (drawDisplay) {
        oled.display();
    }

    if (curEncoderPos != lastEncoderPos) {
        // Encoder moved, set new position
        myLightMeter.lastActivity = millis();  // reset counter
        lastEncoderPos = curEncoderPos;
    }

    // Handle the LUX calculation trigger
    switch (triggerState) {
        case hSRun:
            // handled in onButtonReleased
            break;

        case hSHeld:
            // handled in onButtonReleased
            break;

        default:
            lux = 0;
            triggerState = hSRun;
            break;
    }
}

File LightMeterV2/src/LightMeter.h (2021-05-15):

// Copyright 2018 Dashie <dashie@sigpipe.me>
#ifndef LIGHTMETERV2_SRC_LIGHTMETER_H_
#define LIGHTMETERV2_SRC_LIGHTMETER_H_

// Main Library
#include <Arduino.h>

// Battery Babysitter
#include <SparkFunBQ27441.h>
// Light, Lux, Meter
#include "Adafruit_TSL2591.h"
// For user config
#include <EEPROM.h>
// Oled display
#include <TeensyView.h>
// Input handling
#define ENCODER_OPTIMIZE_INTERRUPTS
#include <Bounce2.h>              // https://github.com/thomasfredericks/Bounce2
#include <Button.h>               // https://github.com/r89m/Button
#include <ButtonEventCallback.h>  // Button too
#include <Encoder.h>     // http://www.pjrc.com/teensy/td_libs_Encoder.html
#include <PushButton.h>  // https://github.com/r89m/PushButton
#include <jled.h>

// Custom OLED routines
#include "OledFunctions.h"

// Pinout declaration of TeensyView module
// The module is in Alternate configuration
#define PIN_RESET 2  // RST
#define PIN_DC 21    // DC
#define PIN_CS 20    // CS
#define PIN_SCK 14   // SCK
#define PIN_MOSI 7   // MOSI

#define ROT_ENC_DETENTS_COUNTS \
    3  // Encoder produce 4 counts per detent
       // But using 3 produce the best result...

#define PIN_POWER_ON 16

/* Calibration constant [Photo]
 * ISO 2720:1973 recommands a K range from 10.6 to 13.4
 * Sekonic, Canon and Nikon uses 12.5
 * Minolta, Kenko and Pentax uses 14
 * Difference between thoses two is 1/6 EV
 * Kevin Agnes used 129 [2591, dome]
 * Kevin Kadooka used 64 [2561, no dome]
 * Previous K was 30
 */
#define KValue 627
/* dashie's notes: it seems weird to me to need a value that high
    I calculated it by getting the lux value from the meter
    Getting f-stop and iso from dslr and time it would expose (by using the meter in "whole frame" not spot)
    And calculating manually my speed value on a calculator by changing the KValue until I get something 
    close from the DSLR one
    */

/* C Calibration constant [Cine/Video]
 * PhotoChemicals used 25 [2591, dome unknown]
 * Kevin Agnes used 129 [2591, dome]
 */
#define CValue 9.5  // Cine

#define DomeMultiplier 1
// Multiplier when using translucid Dome covering the sensor
// The dome is only used for Incident light metering
// Which isn't supported yet

#define SENSOR_INTTIME_DEFAULT TSL2591_INTEGRATIONTIME_200MS
#define SENSOR_INTTIME_HIGH TSL2591_INTEGRATIONTIME_400MS

#define LIPO_CAPACITY 1000  // mAh

// Rotary encoder GREEN / RED LED
#define PIN_LED_OK 11
#define PIN_LED_KO 10

/* Auto sleep after
 * 3600000 = 1h
 *   60000 = 1mn
 *    1000 = 1sec
 */
#define SLEEP_AFTER 3600000

// Menu State
enum MState_t {
    Minit,                   // Initial state page
    MDisplayPhotoValueInit,  // Init page for photo light metering
    MDisplayPhotoValue,      // Page for photo light metering
    MDisplayVideoValueInit,  // Init for video light metering
    MDisplayVideoValue,      // Video light metering
    MSetISOInit,             // Init for ISO Selection
    MSetISO,                 // ISO Selection
    MSystemInit,
    MSystem,  // System informations
    MDisplayLuxValueInit,
    MDisplayLuxValue,  // Lux value only
    MMaryInit,
    MMary,  // <3
    // Not yet implemented
    MFStopRangeInit,
    MFStopRange,  // Select a fStop range from a few pre-determinated
};

// Hold State
enum holdState_t { hSRun, hSHeld };

/*
 * Fuji Body: 22 16 11 8 5.6 4 2.8 2 1.4
 * Fuji 28: 16 11 8 5.6 4 2.8
 * Fuji 80-200: 16 11 8 5.6 3.8
 * Fuji 135: 16 11 8 5.6 4 2.8
 * Fuji 50: 16 11 8 5.6 4 2.8 1.9
 * Soligor 35-140: 22 16 11 8 5.6 3.8
 * Telemar 22A: 22 16 11 8 5.6
 * ARSAT: 22 16 11 8 5.6 3.5
 * MTO: 10.5
 * Warra box: 11
 *
 * Fuji mixed: 22, 16, 11, 8, 5.6, 4, 3.8, 2.8, 2, 1.9, 1.4
 *
 * Full: 22, 20, 18, 16, 14, 13, 11, 10, 10.5, 9, 8, 7.1, 6.3, 5.6, 5, 4.5,
 * 4, 3.8, 3.5, 3.2, 2.8, 2.5, 2.2, 2, 1.9, 1.8, 1.4
 */

enum FS_table {
    TableMto,
    TableWarra,
    TableFuji,
    TableFull  // default
};

// Custom tables
const float fStopTableMto[1] = {10.5};
const float fStopTableWarra[1] = {11};
const float fStopTableFuji[11] = {1.4, 1.9, 2, 2.8, 3.8, 4, 5.6, 8, 11, 16, 22};
// Default table
#define FSTOP_COUNT 27
const float fStopTable[FSTOP_COUNT] = {
    1.4, 1.8, 1.9, 2, 2.2, 2.5,  2.8, 3.2, 3.5, 3.8, 4,  4.5, 5, 5.6,
    6.3, 7.1, 8,   9, 10,  10.5, 11,  13,  14,  16,  18, 20,  22};

// Konvas 1KCP: 8, 12, 16, 24, 25, 32
#define EXPOSURE_COUNT 8
const float exposureTable[EXPOSURE_COUNT] = {
    0.125,        // 8 fps
    0.083333333,  // 12 fps
    0.0625,       // 16 fps
    0.041666666,  // 24 fps
    0.04,         // 25 fps
    0.033333333,  // 30 fps
    0.03125,      // 32 fps
    0.016666666   // 60 fps
};

#define ISO_COUNT 9
uint8_t isoTableSize = ISO_COUNT;
const float isoTable[ISO_COUNT] = {25,  100,  125,  200, 400,
                                   800, 1600, 3200, 6400};

#define LED_OK 0
#define LED_KO 1

// EEprom user config
struct CfgUser {
    FS_table fStops;              // Unused for now
    uint8_t fStopSetting = 14;    // 5.6; Saved on shutdown
    uint8_t exposureSetting = 1;  // 0.04; Saved on shutdown
    uint8_t isoSetting = 5;       // 400; Saved on change
};

class LightMeter {
 public:
    LightMeter(void);
    void process();
    void powerDown(bool);
    void ledStatus(int, int, int);
    void saveConfigUser();

    bool lipoGood;

    double lux;
    uint8_t heartCount;

    uint32_t lastActivity = 0;

    MState_t state;
    holdState_t triggerState;

 private:
    void loadConfigUser();
    void getRawLux();
    void getLuxAndCompute(bool fstop);
    void getLux();
    void blinkLed();
    uint32_t eeprom_crc(uint16_t position);

    // Our Marker to validate EEPROM is valid
    const String progName = "LightMeter";
    int addrConfigUser = 0;      // Always save at position 0 in EEPROM
    uint32_t addrMarker = 2000;  // Store marker at 2000 bytes in EEPROM

    // Static init of the encoder value
    uint32_t lastEncoderPos = -999;

    bool needHigh = 0;  // If High Gain, Hi will be displayed, and gain == 428x
    bool overflow = 0;  // Sensor is saturated and display Overflow

    CfgUser ConfigUser;
};

#endif  // LIGHTMETERV2_SRC_LIGHTMETER_H_

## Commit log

2019-01-04 Remove unused 3D Bezel
    [001shapes.blend, 002FirstTry.blend, PongBezelPrint.stl]
2019-01-04 Switch whole project to PlatformIO
2019-01-08 Fix buttons issue; Use callbacks for the state machine
    [LightMeter.cpp, LightMeter.h]
2019-01-08 Fix trigger state not working
    [LightMeter.cpp, LightMeter.h]
2019-01-08 Add PCB
    [lightmeter-B.Cu.gbr, lightmeter-B.Mask.gbr, lightmeter-B.Paste.gbr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]
2019-01-10 Somewhat fix encoder issue
    [LightMeter.cpp, LightMeter.h]
2019-01-10 Fix drawing for f10.x, move left bracket 5px on the right
    [LightMeter.cpp, LightMeter.h, OledFunctions.h]
2019-01-10 Fix get lux display; Add d0 d1 label
    [LightMeter.cpp]
2019-01-13 Add no-delay timer for LEDs
2019-01-13 Implement led statuses
2019-01-13 Add led ko when shutdown fails
    [LightMeter.cpp, LightMeter.h]
2019-01-15 Switching to TSL2691; Adafruit lib; And another code; Also remove accumulator thing
2019-01-16 Add libreoffice calc I used to get the best K-value
    [fstop lux calc.ods]
2019-01-16 Improved a bit the lux thingy; High/low gain with slow/fast integration time; Added more things to the debug line
    [fstop lux calc.ods]
2019-01-16 Add some calibration notes
    [fstop lux calc.ods]
2019-01-16 Specify calibration is only valid for reflected
2019-01-16 TeensyView alternate mode
2019-01-17 Implement correct led blinking
    [LightMeter.cpp, LightMeter.h]
2020-09-15 Add v1 proto enclosure
    [bottom.stl, cover slides.stl, cover.stl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]
